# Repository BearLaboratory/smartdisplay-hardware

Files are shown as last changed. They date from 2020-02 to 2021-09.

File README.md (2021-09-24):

<h1 align="center" style="font-size:50px;font-weight:bold">SmartDisplay-Hardware</h1>
<p align="center">墨水屏个人显示终端硬件</p>
<p align="center">
    <a href="https://github.com/">
        
    </a>
    <a href="https://www.kicad.org/">
        
    </a> 
    <a href="https://dengyi.pro">
        
    </a>
</p>

## 描述

smartdisplay硬件基于ESP32及2.9寸墨水屏，拥有WiFi及蓝牙BLE功能。

可通过WiFi连接网络请求相关数据，同时可以通过蓝牙控制系统。

## 硬件设计

## BUG

+ 充电芯片TP4054充电功率过小
> 充电功率TP4054只有500ma,导致边冲边放无法更好给电池充电。

+ 无时钟芯片
> 无时钟芯片导致时间不准确

## 固件及APP

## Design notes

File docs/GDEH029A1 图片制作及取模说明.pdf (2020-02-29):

## GDE029A1 图片制作及取模说明

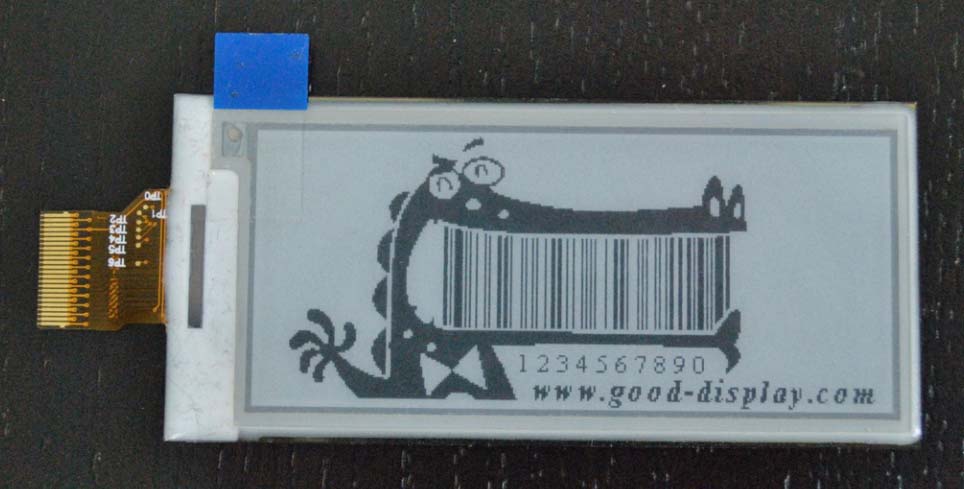
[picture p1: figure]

图一

### 以实现图一效果为例，简要介绍图片制作和取模。

一、 | 图片制作
| 该款屏不支持灰度，在制作图片的时候，需要做成 296*128 分辨率的纯黑白图
| 片，需要显示的内容做成黑色，不显示的内容做成白色，保存成.bmp 位图文件。Bmp
| 文件参见 296128‐12.bmp。
二、 | 取模
| 取模可以采用 image2lcd 软件，压缩包里面有。取模参数设置界面见图二：

1、 打开 image2lcd，调入需要取模的图片；

2、 输出数据类型：选择“C 语言数组（*.c）”；

3、 扫描方式：选择“垂直扫描”；

4、 输出灰度：选择“单色”；

5、 最大宽度和高度：选择“296”、“128”，选择后需要点击后面的箭头确认；

6、 | 这 5 项全不要打钩；

7、 正显（白底黑字），则“颜色反转”打钩；负显（黑底白字）则不需要打钩。

8、 点击“保存”，把转换后的数组存到扩展名为“.C”文件；

9、 最后把文件“.C”中的数组替换掉程序中对应的数组。

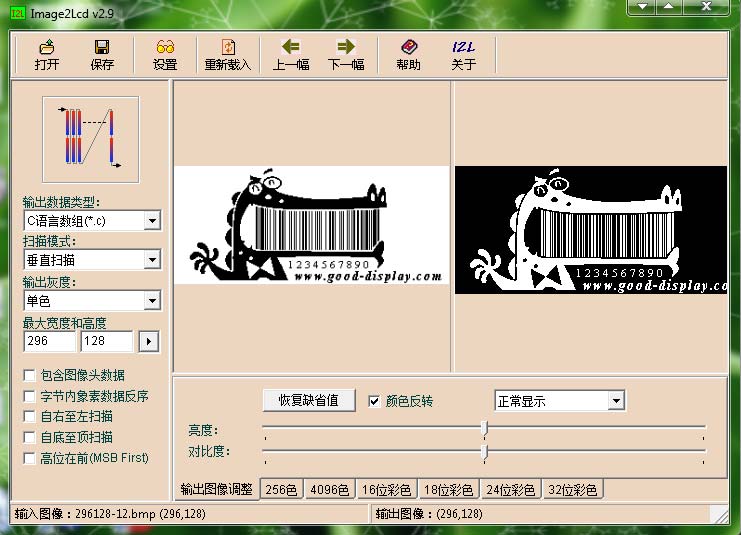
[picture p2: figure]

图二

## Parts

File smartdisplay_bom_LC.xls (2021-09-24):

Comment型号 | Designator位号 | Footprint封装 | 嘉立创元件编号(可不要此列)
0.1uf | C5,C16,C3, | 0603 | C268011
4.7uF | C8,C4, | 0603 | C1705
1uF | C9,C15,C14,C13,C12,C11,C10,C7,C2,C1,C17,C6, | 0603 | C15849
LED-green | D2, | 0603 | C87326
MBR0530 | D5,D1,D4, | SOD-123 | C77336
LED-red | D6,D3, | 0603 | C72044
10uH | L1, | SMD | C38117
SI1308EDL | Q1, | SOT-323 | C469327
10k | R4,R8,R7,R6,R9,R10,R2,R1,R3, | 0603 | C98220
3 | R5, | 0603 | C126358
DDC114TU-7-F | U1, | SOT-363 | C526523
ch340k | U2, | ESSOP-10 | C968586
24pinconnecter | U3, | P=0.5mm | C262643
ESP-32S | U4, | SMD-38 | C473012
SHT31-DIS | U5, | DFN-8_EP_3x3mm | C80862
ME6211C33M5G-N | U6, | SOT-23-5 | C82942
TP4054 | U7, | SOT-23-5L | C668215
USB_C_Receptacle_USB2.0 | J2, | 8.94*7.3mm | C165948

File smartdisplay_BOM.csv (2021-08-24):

Comment | Description | Designator | Footprint | LibRef | Pins | Quantity | PartNumber | url
0.1uf | desc | C5,C16,C3, | C_0603_1608Metric | libref | 2 | 3
4.7uF | desc | C8,C4, | C_0603_1608Metric | libref | 2 | 2
1uF | desc | C9,C15,C14,C13,C12,C11,C10,C7,C2,C1,C17,C6, | C_0603_1608Metric | libref | 2 | 12
LED-green | desc | D2, | D_0603_1608Metric | libref | 2 | 1
MBR0530 | desc | D5,D1,D4, | D_SOD-123 | libref | 2 | 3
LED-red | desc | D6,D3, | D_0603_1608Metric | libref | 2 | 2
Conn_01x01_Female | desc | J3,J1, | largepoint | libref | 1 | 2
10uH | desc | L1, | L_Coilcraft_XxL4040 | libref | 2 | 1
SI1308EDL | desc | Q1, | SOT-23 | libref | 3 | 1
10k | desc | R4,R8,R7,R6,R9,R10,R2,R1,R3, | R_0603_1608Metric | libref | 2 | 9
3 | desc | R5, | R_0603_1608Metric | libref | 2 | 1
SW_Push | desc | SW1, | bt-342 | libref | 2 | 1
DDC114TU-7-F | desc | U1, | SOT-363_SC-70-6 | libref | 6 | 1
ch340k | desc | U2, | ESSOP-10_3.9x4.9mm_P1.00mm | libref | 11 | 1
24pinconnecter | desc | U3, | epd-24pin | libref | 26 | 1
ESP-32S | desc | U4, | ESP32-WROOM-32 | libref | 39 | 1
SHT31-DIS | desc | U5, | Sensirion_DFN-8-1EP_2.5x2.5mm_P0.5mm_EP1.1x1.7mm | libref | 10 | 1
ME6211C33M5G-N | desc | U6, | SOT-23-5 | libref | 5 | 1
TP4054 | desc | U7, | SOT-23-5 | libref | 5 | 1
Through Hole Items
USB_C_Receptacle_USB2.0 | desc | J2, | USB_C_Receptacle_HRO_TYPE-C-31-M-12 | libref | 22 | 1

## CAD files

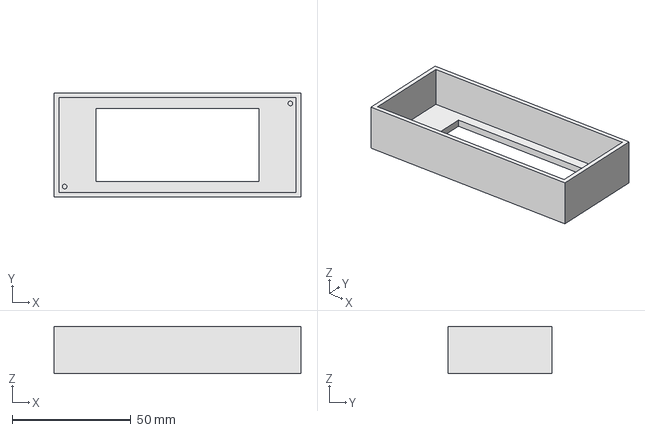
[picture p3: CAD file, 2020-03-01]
shell/smartdisplayshell.FCStd
104.0 x 44.0 x 20.0 mm

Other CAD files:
shell/boxshell.stl

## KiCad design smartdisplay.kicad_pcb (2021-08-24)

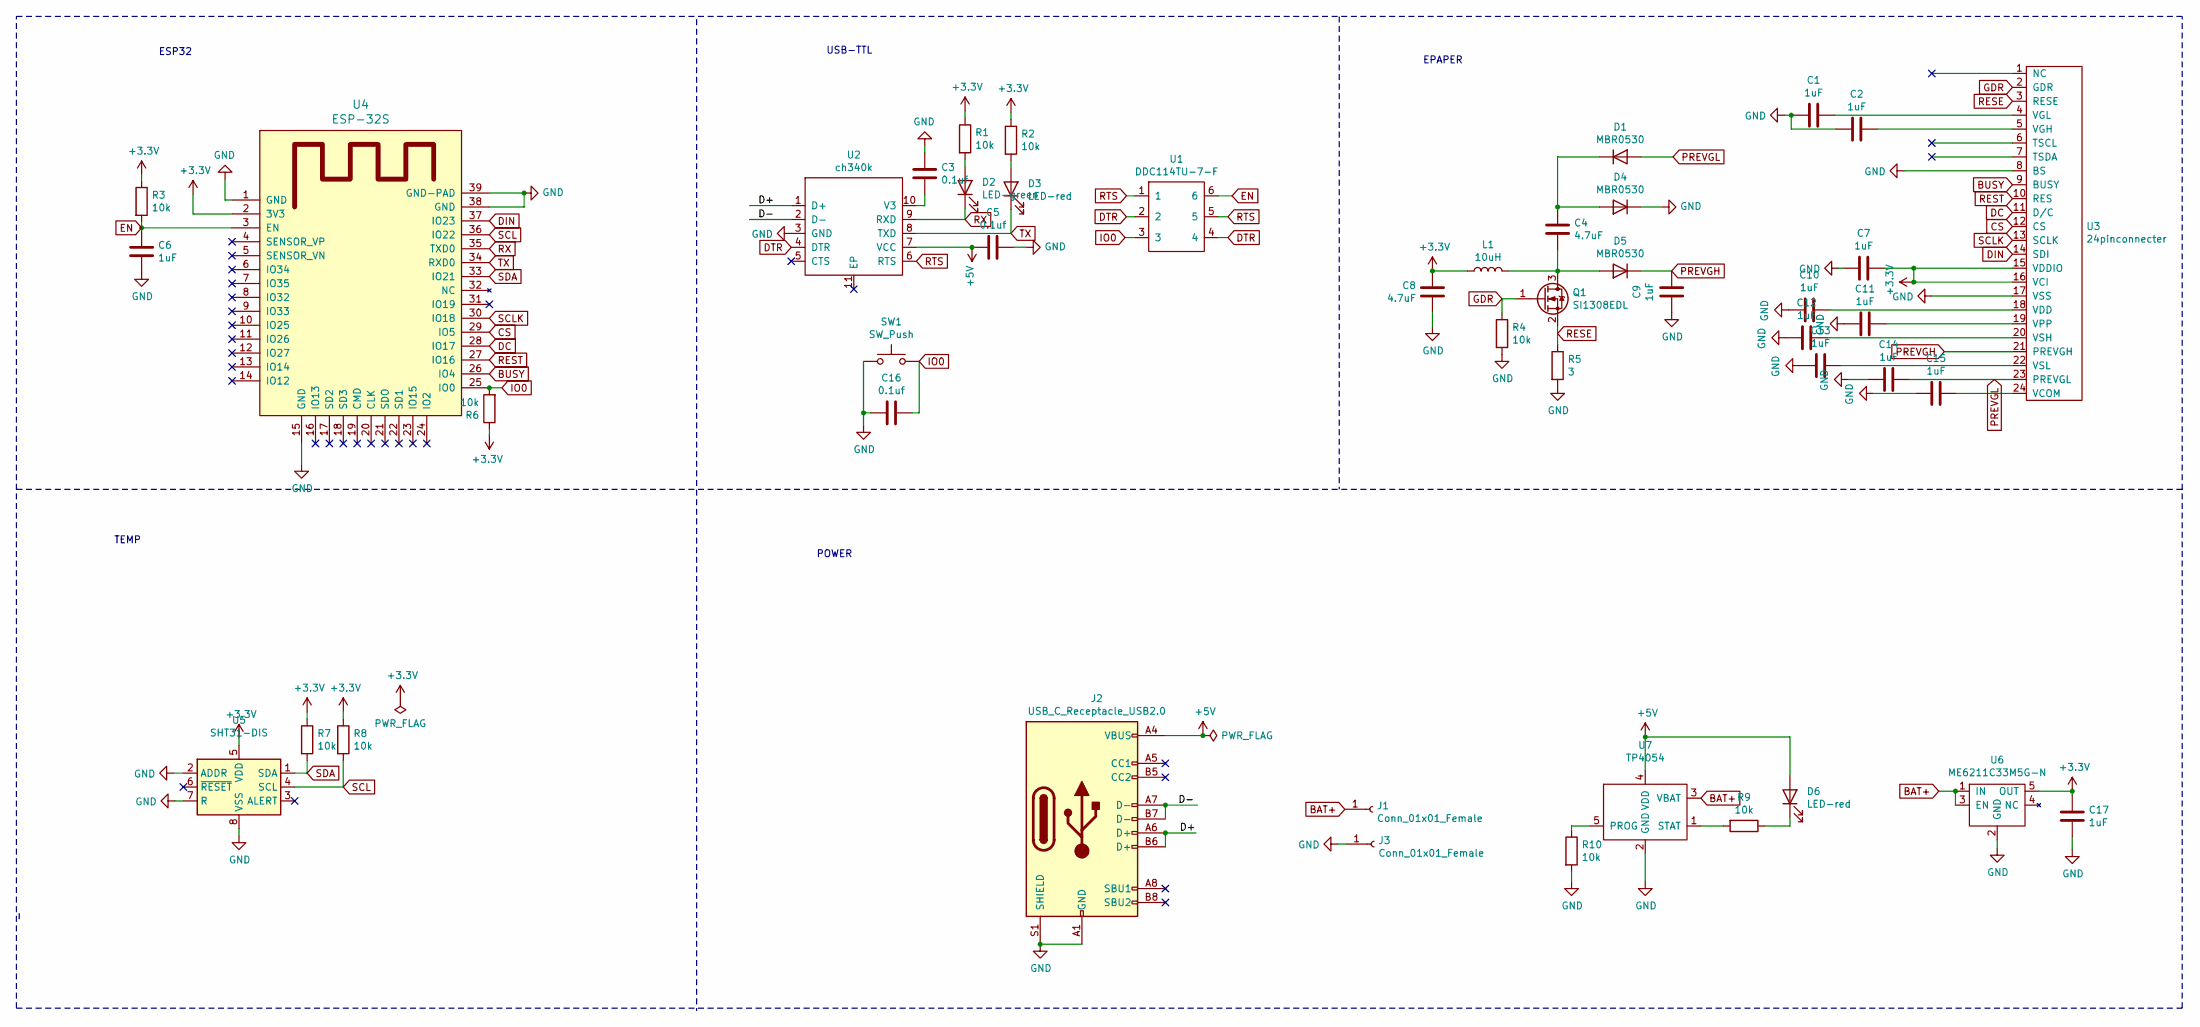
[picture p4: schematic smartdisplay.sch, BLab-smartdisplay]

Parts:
C1, C2, C6, C7, C9, C10, C11, C12, C13, C14, C15, C17: 1uF; C_0603_1608Metric
C3, C5, C16: 0.1uf; C_0603_1608Metric
C4, C8: 4.7uF; C_0603_1608Metric
D1, D4, D5: MBR0530; D_SOD-123
D2: LED-green; D_0603_1608Metric
D3, D6: LED-red; D_0603_1608Metric
J1, J3: Conn_01x01_Female; largepoint
J2: USB_C_Receptacle_USB2.0; USB_C_Receptacle_HRO_TYPE-C-31-M-12
L1: 10uH; L_Coilcraft_XxL4040
Q1: SI1308EDL; SOT-23
R1, R2, R3, R4, R6, R7, R8, R9, R10: 10k; R_0603_1608Metric
R5: 3; R_0603_1608Metric
SW1: SW_Push; bt-342
U1: DDC114TU-7-F; SOT-363_SC-70-6
U2: ch340k; ESSOP-10_3.9x4.9mm_P1.00mm
U3: 24pinconnecter; epd-24pin
U4: ESP-32S; ESP32-WROOM-32
U5: SHT31-DIS; Sensirion_DFN-8-1EP_2.5x2.5mm_P0.5mm_EP1.1x1.7mm
U6: ME6211C33M5G-N; SOT-23-5
U7: TP4054; SOT-23-5

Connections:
+3V3: C7.1, C8.2, C17.1, L1.1, R1.1, R2.1, R3.1, R6.1, R7.1, R8.1, U3.15 (VDDIO), U3.16 (VCI), U4.2 (3V3), U5.5 (VDD), U6.5 (OUT)
+5V: C5.1, D6.2 (A), J2.A4 (VBUS), J2.A9 (VBUS), J2.B4 (VBUS), J2.B9 (VBUS), U2.7 (VCC), U7.4 (VDD)
/D+: J2.A6 (D+), J2.B6 (D+), U2.1 (D+)
/D-: J2.A7 (D-), J2.B7 (D-), U2.2 (D-)
BAT+: J1.1, U6.1 (IN), U6.3 (EN), U7.3 (VBAT)
BUSY: U3.9 (BUSY), U4.26 (IO4)
CS: U3.12 (CS), U4.29 (IO5)
DC: U3.11 (D/C), U4.28 (IO17)
DIN: U3.14 (SDI), U4.37 (IO23)
DTR: U1.2, U1.4, U2.4 (DTR)
EN: C6.1, R3.2, U1.6, U4.3 (EN)
GDR: Q1.1 (G), R4.1, U3.2 (GDR)
GND: C1.2, C2.2, C3.1, C5.2, C6.2, C7.2, C8.1, C9.2, C10.2, C11.2, C12.2, C13.2, C14.2, C15.2, C16.1, C17.2, D4.1 (K), J2.A1 (GND), J2.A12 (GND), J2.B1 (GND), J2.B12 (GND), J2.S1 (SHIELD), J3.1, R4.2, R5.2, R10.2, SW1.1, U2.3 (GND), U3.8 (BS), U3.17 (VSS), U4.1 (GND), U4.15 (GND), U4.38 (GND), U4.39 (GND-PAD), U5.2 (ADDR), U5.7 (R), U5.8 (VSS), U5.9 (VSS), U6.2 (GND), U7.2 (GND)
IO0: C16.2, R6.2, SW1.2, U1.3, U4.25 (IO0)
unnamed: C1.1, U3.4 (VGL)
unnamed: C2.1, U3.5 (VGH)
unnamed: C3.2, U2.10 (V3)
unnamed: C4.1, D1.1 (K), D4.2 (A)
unnamed: C4.2, D5.2 (A), L1.2, Q1.3 (D)
unnamed: C10.1, U3.18 (VDD)
unnamed: C11.1, U3.19 (VPP)
unnamed: C12.1, U3.20 (VSH)
unnamed: C13.1, U3.22 (VSL)
unnamed: C15.1, U3.24 (VCOM)
unnamed: D2.2 (A), R1.2
unnamed: D3.2 (A), R2.2
unnamed: D6.1 (K), R9.1
unnamed: R9.2, U7.1 (STAT)
unnamed: R10.1, U7.5 (PROG)
PREVGH: C9.1, D5.1 (K), U3.21 (PREVGH)
PREVGL: C14.1, D1.2 (A), U3.23 (PREVGL)
RESE: Q1.2 (S), R5.1, U3.3 (RESE)
REST: U3.10 (RES), U4.27 (IO16)
RTS: U1.1, U1.5, U2.6 (RTS)
RX: D2.1 (K), U2.9 (RXD), U4.35 (TXD0)
SCL: R8.2, U4.36 (IO22), U5.4 (SCL)
SCLK: U3.13 (SCLK), U4.30 (IO18)
SDA: R7.2, U4.33 (IO21), U5.1 (SDA)
TX: D3.1 (K), U2.8 (TXD), U4.34 (RXD0)

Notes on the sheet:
ESP32
USB-TTL
EPAPER
TEMP
POWER

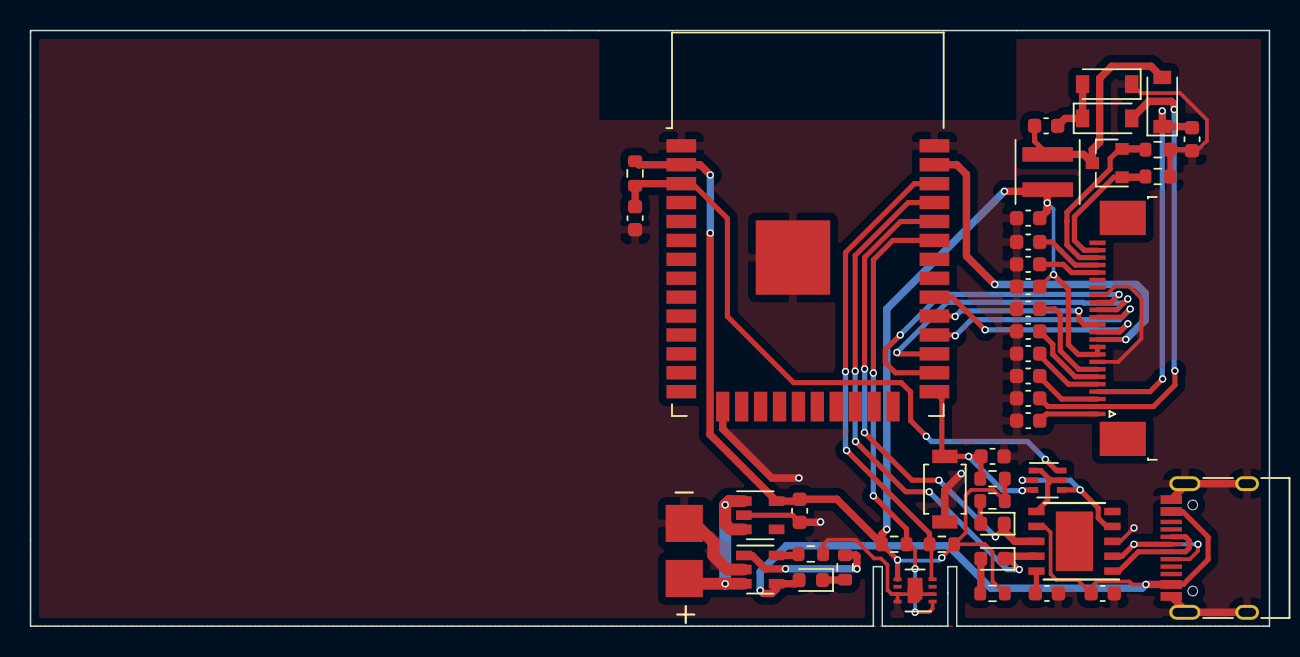
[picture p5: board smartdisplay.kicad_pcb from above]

Board: 2 copper layers, 83.2 x 40.0 mm, 46 parts (0 on the bottom side), 39 nets.

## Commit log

2020-02-29 init commit
    [smartdisplay-B_Cu.gbr, smartdisplay-B_Mask.gbr, smartdisplay-B_Paste.gbr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]
2020-02-29 修改readme
2020-03-01 新增外壳freecad设计
    [boxshell.stl, smartdisplayshell.FCStd]
2020-03-01 修改外壳前盖设计
    [boxshell.stl, smartdisplayshell.FCStd]
2021-08-24 finish v1.0
    [smartdisplay-B_Cu.gbr, smartdisplay-B_Mask.gbr, smartdisplay-B_Paste.gbr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]

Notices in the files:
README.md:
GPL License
